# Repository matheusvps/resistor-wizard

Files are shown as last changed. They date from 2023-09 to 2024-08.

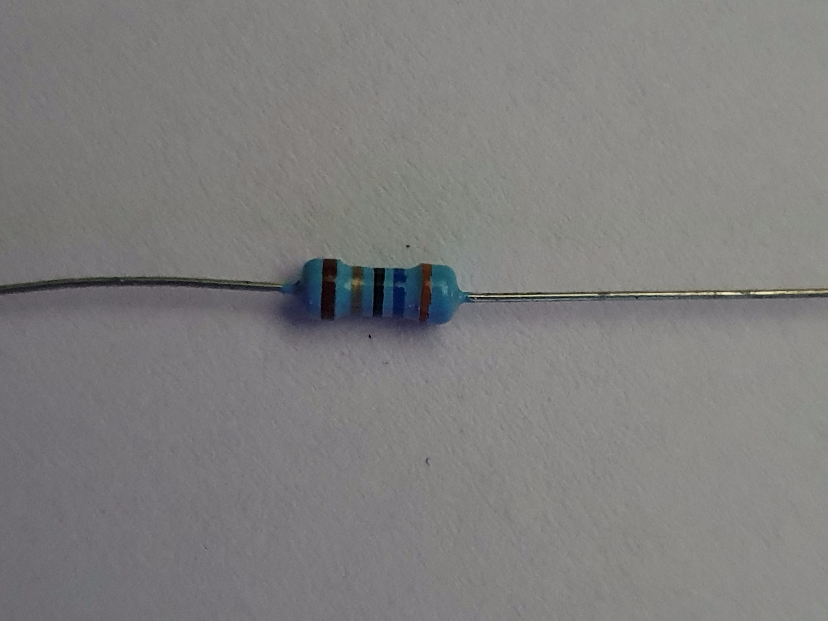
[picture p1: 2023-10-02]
Backend/Functionality Tests/0002.png

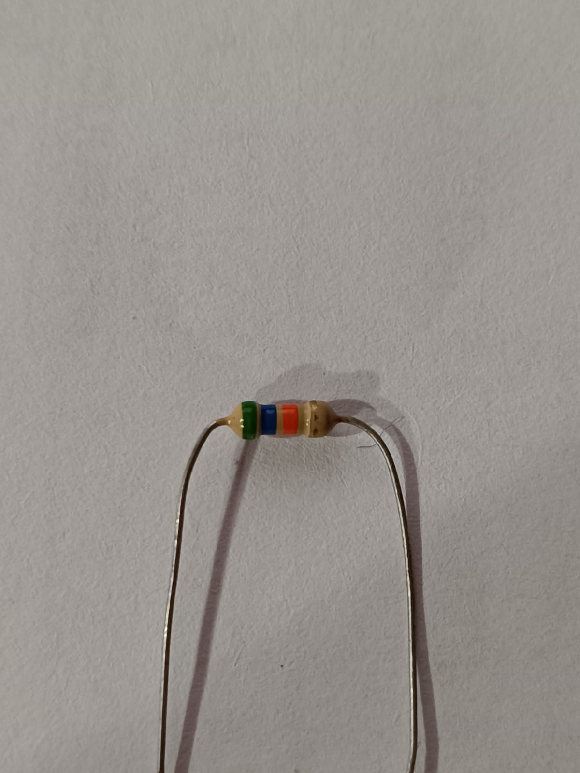
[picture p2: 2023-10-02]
Backend/Functionality Tests/0015.jpg

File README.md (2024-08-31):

# Resistor Wizard Project 🧙‍♂️

## Overview

This GitHub repository hosts the code for the Resistor Sorter project, developed as part of the Integration Workshops 1 subject. The system consists of a resistor sorting mechanism that allows users to insert indivual resistors into a small slit and select up to six resistance values to sort them into. It's implemented as a web application, with its frontend built using CSS, HTML, Javascript, and React framework. Both the server and subsequent backend processes are handled by a Raspberry Pi 3B running Flask in Python. The Pi photographs the resistors through a USB camera and extracts color and position data using Computer Vision (CV) to determine its resistance. To optimise the process of locating and classifying hue values under different lighting conditions, Machine Learning (ML) techniques were used.

## Team Members

- **Matheus Passos** - Frontend Development and Project Integration
- **Jhony Minetto** - Backend Development, Algorithm Design and ML Training
- **Ricardo Marthus** - Conception of 3D models and Image Labelling for the dataset

## Project Components

### Frontend

The frontend of the Resistor Wizard is composed of the web app user interface where resistance values can be selected and the hardware abd mechanical system controlled. The user interacts with the system primarily through this web interface.

### Backend

The backend of the project runs on a Raspberry Pi 3B server and is implemented in Python using the Flask framework. It handles the following tasks:

- Determining Resistor's position and color bands location using ML (YOLOv8 network trained on PyTorch ML framework)
- Color recognition using OpenCV
- Communication with the frontend

### Machine-Learning Models

The ML models are a crucial component of this project. They have been trained by our dedicated team to recognize resistors and resistor color bands accurately. The data used to train the models themselves is majoritarily self-provided (meaning we created and labelled the data ourselves). The complete datasets can be visited at <a href="https://universe.roboflow.com/uni-vug0c/metal-film-leaded-resistors-dataset">resistor dataset</a> and <a href="https://universe.roboflow.com/jhony-minetto-arajo/metal-film-leaded-resistor-color-bands">resistor color bands dataset</a>.

## Getting Started

To run this project locally or on your own Raspberry Pi server, follow these steps:

1. Clone this repository: `git clone https://github.com/yourusername/resistor-sorter.git`
2. Set up the frontend environment and dependencies.
   - Navigate to the `frontend` directory.
   - Install dependencies using npm or yarn: `npm install` or `yarn install`.
   - Start the frontend application: `npm start` or `yarn start`.
   
3. Set up the backend environment and dependencies on your Raspberry Pi.
   - Navigate to the `backend` directory.
   - Install Python dependencies: `pip install -r requirements.txt`.
   - Start the Flask server: `python app.py`.
   
4. Ensure the necessary hardware components are connected and configured on your Raspberry Pi for resistor input.

5. Access the web application in your browser and start using the Resistor Sorter.

## Contributions

We welcome contributions and improvements from the community. If you'd like to contribute to this project, please fork the repository, make your changes, and submit a pull request. Your contributions will be greatly appreciated.

Feel free to contact us if you have any questions or need assistance with the project.

Happy sorting!

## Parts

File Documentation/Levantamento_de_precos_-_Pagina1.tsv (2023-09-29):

Componentes | Quantidade | Custo Unitário R$ | Custo Total R$ | Adquirido
Raspberry Pi 3B | 1 | R$ 500,00 | R$ 500,00 | Sim
Motor de passo NEMA 17 | 2 | R$ 60,00 | R$ 120,00 | Sim
Driver de motor de passo | 2 | R$ 10,00 | R$ 20,00 | Sim
Kit 20 Placas MDF (150x210x3 mm) | 1 | R$ 32,00 | R$ 32,00 | Não
Placa de fenolite | 1 | R$ 10,00 | R$ 10,00 | Sim
Câmera Logitech 1080p | 1 | R$ 160,00 | R$ 160,00 | Sim
Placa de acrílico | 1 | R$ 30,00 | R$ 30,00 | Não
Resistores (cartela) | 1 | R$ 0,50 | R$ 0,50 | Sim
LEDs | 6 | R$ 0,30 | R$ 3,00 | Sim
MOSFET IRLZ44N | 1 | R$ 13,70 | R$ 13,70 | Sim
Regulador de tensão L7805 | 1 | R$ 3,30 | R$ 3,30 | Sim
Valor total |  |  | R$ 892,50

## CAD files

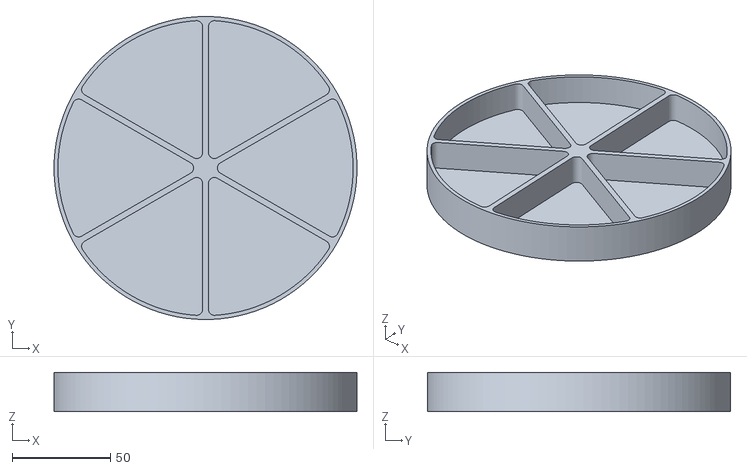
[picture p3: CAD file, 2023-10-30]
Backend/Modelos 3D/Armazenador.stl
154.0 x 154.0 x 20.0

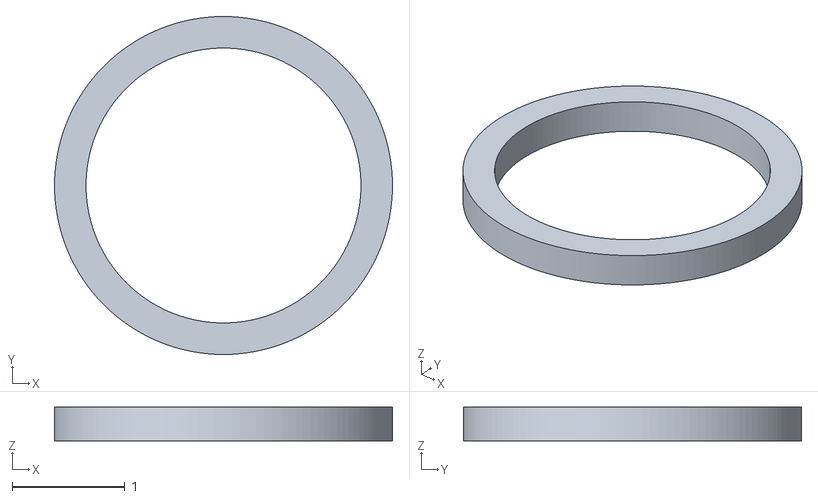
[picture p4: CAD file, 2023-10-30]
Backend/Modelos 3D/pcb_draw_test.stl
3.00 x 3.00 x 0.3

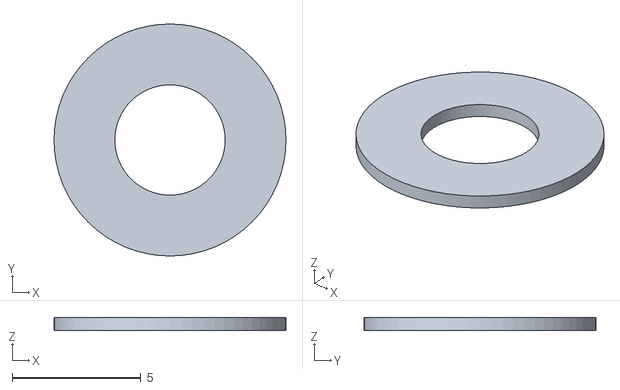
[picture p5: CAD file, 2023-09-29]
Backend/Modelos 3D/Arruela.stl
9.00 x 9.00 x 0.5

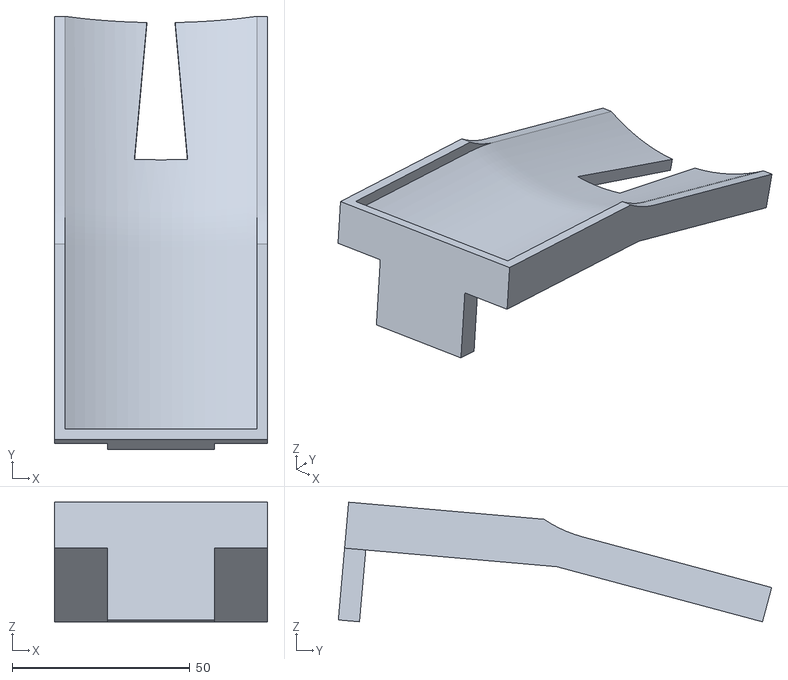
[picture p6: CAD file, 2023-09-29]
Backend/Modelos 3D/Dispenser_supported.stl
60.0 x 122.1 x 33.7

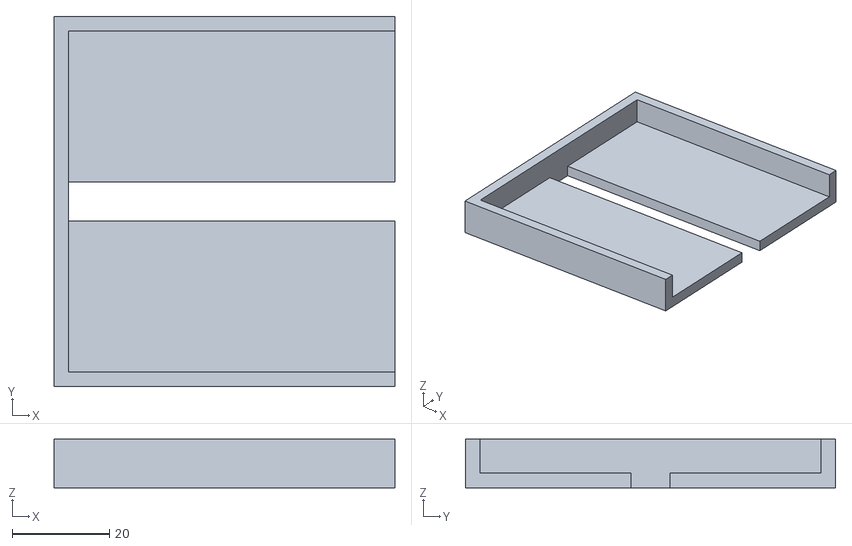
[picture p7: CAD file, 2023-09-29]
Backend/Modelos 3D/Dispenser_v3.stl
70.0 x 76.0 x 10.0

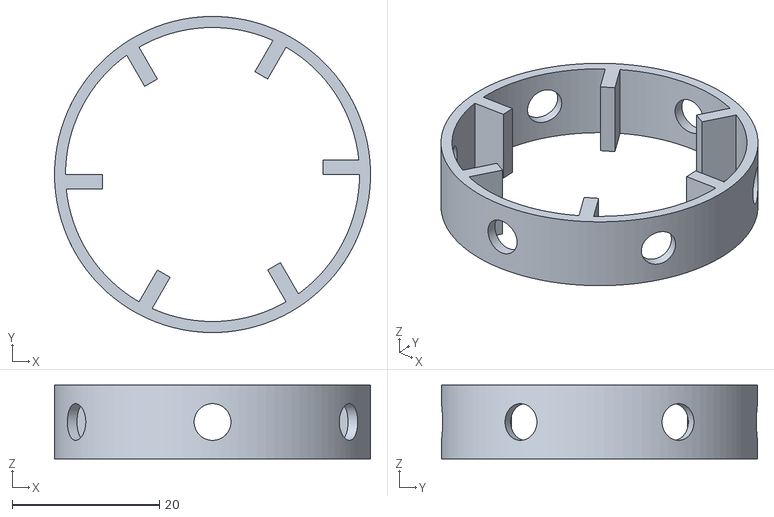
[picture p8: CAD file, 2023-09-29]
Backend/Modelos 3D/led_housing.stl
43.0 x 43.0 x 10.0

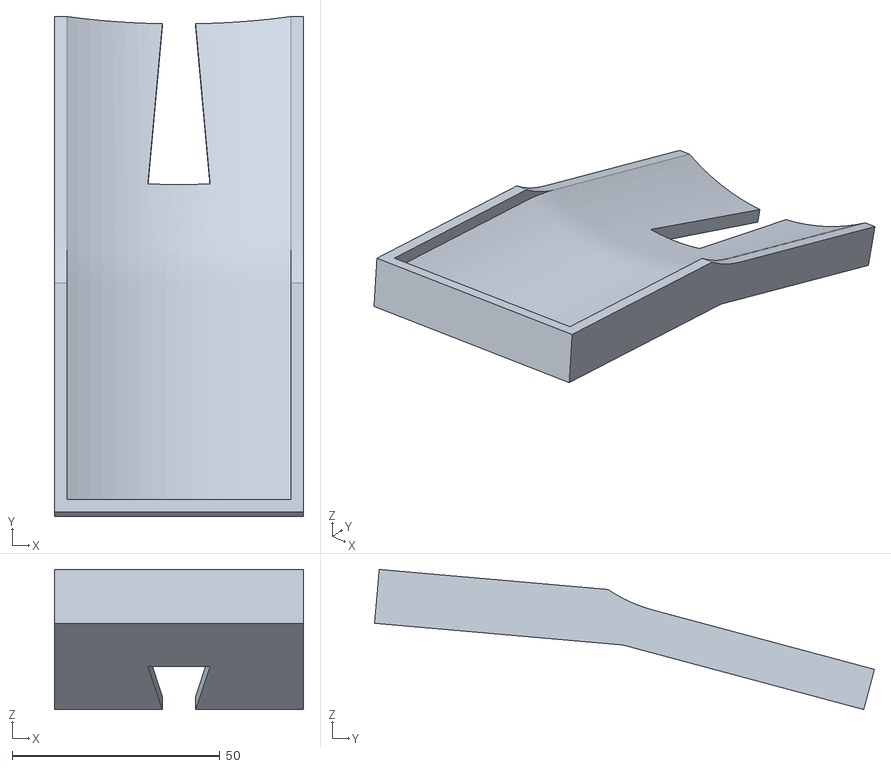
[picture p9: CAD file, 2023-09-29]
Backend/Modelos 3D/Dispenser.stl
60.0 x 120.3 x 33.7

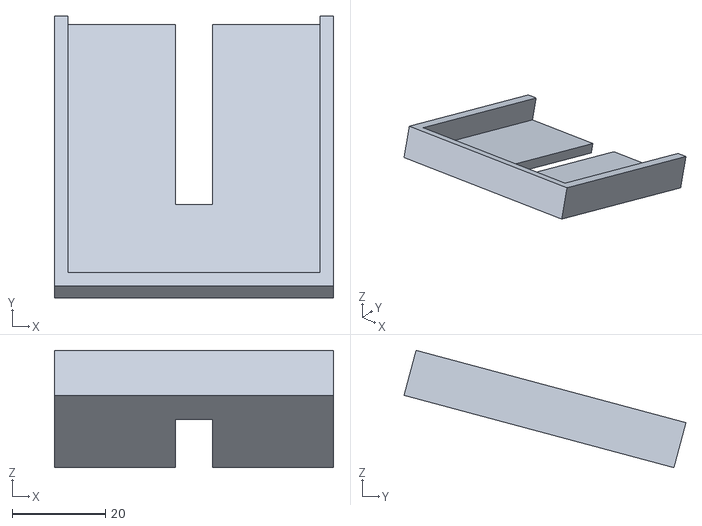
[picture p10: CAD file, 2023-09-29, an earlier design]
Backend/Modelos 3D/Dispenser_v2.stl
60.0 x 60.5 x 25.2

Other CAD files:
Backend/Modelos 3D/dispenser.blend

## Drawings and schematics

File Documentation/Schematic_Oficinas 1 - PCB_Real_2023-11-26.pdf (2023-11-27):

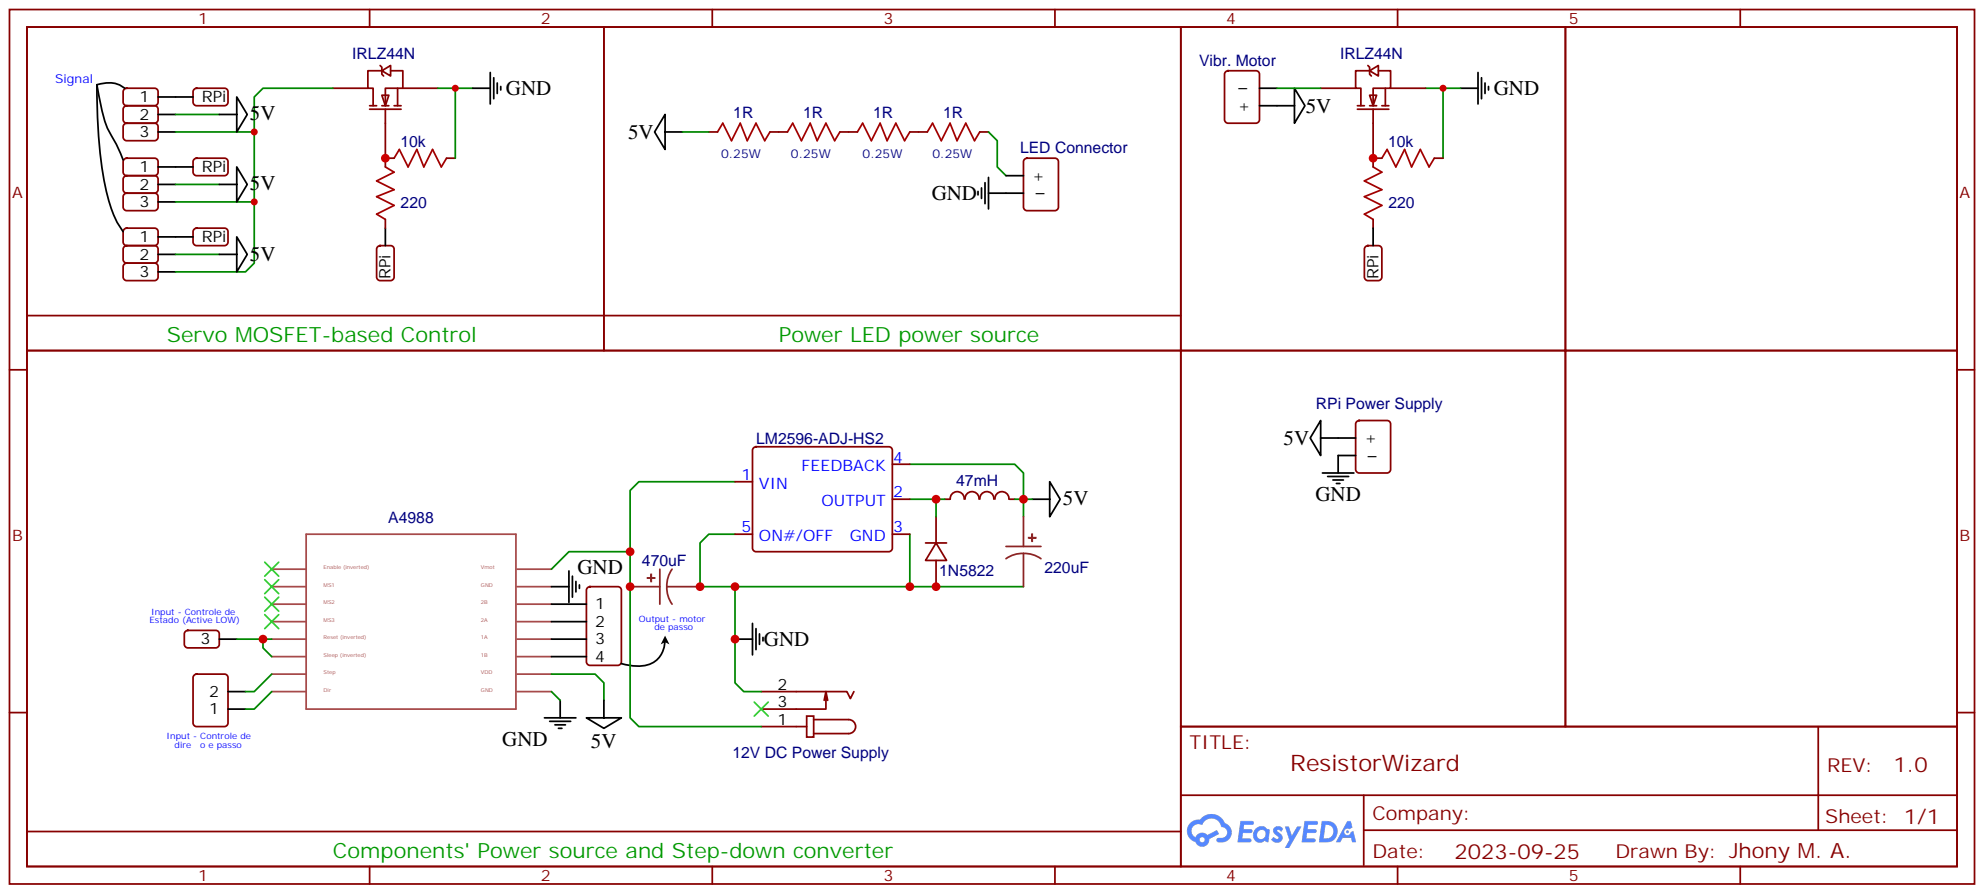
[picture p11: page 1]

Components' Power source and Step-down converter

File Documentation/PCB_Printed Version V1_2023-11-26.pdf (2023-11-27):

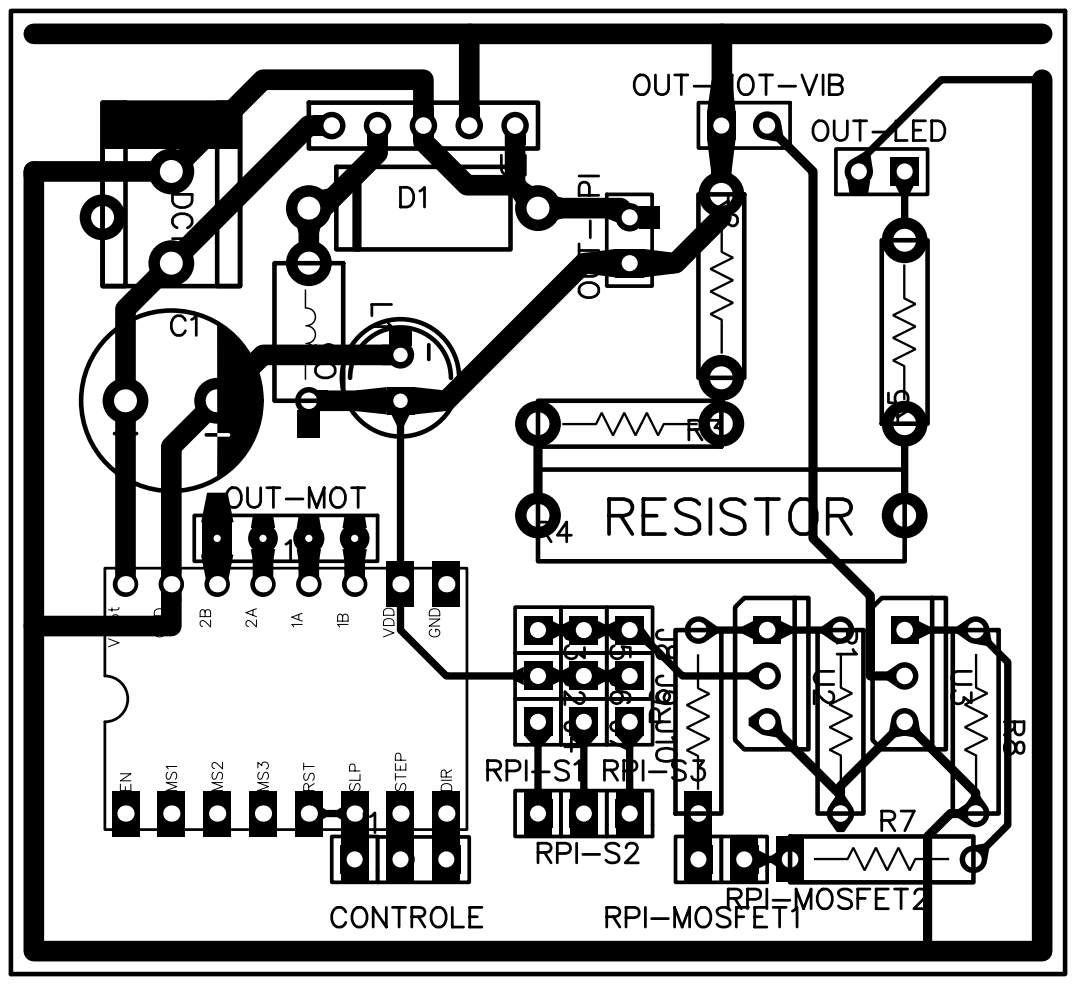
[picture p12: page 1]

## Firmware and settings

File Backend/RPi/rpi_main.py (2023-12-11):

# Main code for Raspberry Pi Model 3B+ -->
#  * Servos and motor control
#  * Camera and light control
#  * Resistor recognition
# ----------------------------------------------------------- #
from globals import *
from utils import *

# ----------------------------------------------------------- #
def run_receiver(rec: Receiver):
    rec.start()

def main():
    camera = Camera()
    motor = Motor(powerSaving=False)
    dispenser = Dispenser()
    plataforma = Plataforma()

    # 0: STOP
    # 1: RUNNING
    # 2: PAUSED
    # 3: EXIT
    is_running = Value('i', 0)  
    # Define the structure of the shared array (list of 5 dictionaries)
    array_size = 5

    # Create a shared array of bytes
    resistances = Array('i', array_size)
    margins = Array('i', array_size)

    receiver = Receiver(port=PORT, ip=IP, is_running=is_running, array_size=array_size, resistances=resistances, margins=margins)
    killer = Killer(is_running=is_running)
    killer.appendObj(camera)
    killer.appendObj(motor)
    killer.appendObj(dispenser)
    killer.appendObj(plataforma)
    killer.appendObj(GPIO)

    if '--no-server' not in sys.argv:
        receiver_process = Process(target=run_receiver, args=(receiver,))
        receiver_process.start()
        killer.appendProc(receiver_process)
    else:
        receiver.is_running.value = 1 # type: ignore
    
    # Loads Recognition models
    cropper = YOLO(yolo_cropper)
    color_bands = YOLO(yolo_segment)

    motor.home()
    camera.start()
    if '--no-renew' not in sys.argv:
        motor.move(100)  # Moves the motor to the position where the screw can be accessed for removal
        plataforma.eject()
    
    started = False
    while receiver.is_running.value != 3: # type: ignore
        while receiver.is_running.value != 1 and receiver.is_running.value != 3: # type: ignore
            sleep(0.1)
        
        if not started:  # Clears terminal window to facilitate reading
            os.system("clear")
            started = True

        for i in range(len(receiver.resistances)):
            motor.storages[i] = [receiver.resistances[i], receiver.margins[i], motor.storages[i][2]]
        print(f"Motor storages: {motor.storages}")

        no_resistor_accum = 0
        while receiver.is_running.value == 1 and no_resistor_accum < 3: # type: ignore
            if '--no-renew' not in sys.argv:
                with concurrent.futures.ThreadPoolExecutor() as executor:
                    func1 = executor.submit(dispenser.drop) # Drops ONE resistor onto the platform
                    func2 = executor.submit(motor.shake)  # Shakes the motor while dropping the resistor
                    # Wait for both to complete
                    concurrent.futures.wait([func1, func2])

            sleep(0.5)  # Waits for the resistor to fall onto the platform
            ret, frame = camera.capture()
            ret, frame = camera.capture()
            if not ret:
                for _ in range(3):
                    ret, frame = camera.capture()
                    if ret:
                        break
                    sleep(0.5)
                if not ret:
                    animate_dots("Couldn't retrieve frame from stream", duration=3)
                    raise Exception("Camera Failure.")
            
            oriented = check_orientation(frame)

            Image.fromarray(cv.cvtColor(oriented, cv.COLOR_BGR2RGB)).save(tmp_photo)

            resistor = dict()

            # Runs crop detection model on file
            cropped_infr = cropper(tmp_photo, conf=0.6)
            # Crops and saves original file to a temporary location
            if len(cropped_infr[0].boxes.data):
                print("\033[92m \n\tDetected a resistor\033[0m")
                cropped = cropImage(cv.imread(tmp_photo), cropped_infr[0].boxes.cpu().data[0])
                # Performs white-balancing on image
                balanced = white_balance(cropped)
                Image.fromarray(cv.cvtColor(balanced, cv.COLOR_BGR2RGB)).save(tmp_crop)
                # Runs color bands segmentation model on cropped inference
                colorbands_infr = color_bands(tmp_crop, conf=0.5, iou=0.3)

                try:
                    # Gets masks objects from the inference
                    masks = get_segmentation_masks(tmp_crop, colorbands_infr)
                    # Sorts the masks by distance (it doesn't have a way to 
                    #    know in which direction to start, so by default it 
                    #    uses the leftmost (0,0) point as a beginning.
                    ordered = order_masks(masks, colorbands_infr)

                    for i in range(len(ordered)):
                        color = retrieve_color(cvtBGR2HSV(ordered[i].avgColor))
                        resistor[i] = color
                        print(f"Index: {ordered[i].index} \t HSV: {cvtBGR2HSV(ordered[i].avgColor, paint=True)} \t Predicted: {color}")
                except Exception as e:
                    print(e)

                # Retrieves the resistance value and moves motor accordingly
                ret, resistance = get_resistance(resistor)
                print(f"\033[91m \n\tDetected Resistance: {resistance}\n\033[0m")
                found_slot = motor.find_slot(resistance)
                if not found_slot:
                    print(f"No suitable destination for the resistor...")
                no_resistor_accum = 0
            else:
                # Handles stopping condition when no resistors are 'seen' on image recognition
                no_resistor_accum += 1
                print(f"\033[91m\n\tCouldn't find a resistor, totalling {no_resistor_accum} empty images\n\033[0m")

            if '--no-renew' not in sys.argv:
                plataforma.eject()

    # CLOSING
    motor.move(100)  # Moves the motor to the position where the screw can be accessed for removal
    camera.__del__()
    dispenser.__del__()
    GPIO.__del__()
    if '--no-server' not in sys.argv:
        receiver_process.terminate()


if __name__=="__main__":
    main()

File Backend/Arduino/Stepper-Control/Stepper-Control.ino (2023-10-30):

/* Example sketch to control a stepper motor with A4988 stepper motor driver 
   and Arduino without a library. More info: https://www.makerguides.com */

// Define stepper motor connections and steps per revolution:
#define dirPin 2
#define stepPin 3
#define stepsPerRevolution 200

void setup() {
  // Declare pins as output:
  pinMode(stepPin, OUTPUT);
  pinMode(dirPin, OUTPUT);
}

void loop() {
  // Set the spinning direction clockwise:
  digitalWrite(dirPin, HIGH);

  // Spin the stepper motor 1 revolution slowly:
  for (int i = 0; i < stepsPerRevolution; i++) {
    // These four lines result in 1 step:
    digitalWrite(stepPin, HIGH);
    delayMicroseconds(2000);
    digitalWrite(stepPin, LOW);
    delayMicroseconds(2000);
  }

  delay(1000);

  // Set the spinning direction counterclockwise:
  digitalWrite(dirPin, LOW);

  // Spin the stepper motor 1 revolution quickly:
  for (int i = 0; i < stepsPerRevolution; i++) {
    // These four lines result in 1 step:
    digitalWrite(stepPin, HIGH);
    delayMicroseconds(1000);
    digitalWrite(stepPin, LOW);
    delayMicroseconds(1000);
  }

  delay(1000);

  // Set the spinning direction clockwise:
  digitalWrite(dirPin, HIGH);

  // Spin the stepper motor 5 revolutions fast:
  for (int i = 0; i < 5 * stepsPerRevolution; i++) {
    // These four lines result in 1 step:
    digitalWrite(stepPin, HIGH);
    delayMicroseconds(500);
    digitalWrite(stepPin, LOW);
    delayMicroseconds(500);
  }

  delay(1000);

  // Set the spinning direction counterclockwise:
  digitalWrite(dirPin, LOW);

  //Spin the stepper motor 5 revolutions fast:
  for (int i = 0; i < 5 * stepsPerRevolution; i++) {
    // These four lines result in 1 step:
    digitalWrite(stepPin, HIGH);
    delayMicroseconds(500);
    digitalWrite(stepPin, LOW);
    delayMicroseconds(500);
  }

  delay(1000);
}

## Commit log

2023-09-07 resistor colors detection - without dynamic image
2023-09-08 resistor color change
2023-09-29 Added Docs: reports, schematics and simulation objs
    [Levantamento_de_precos_-_Pagina1.tsv]
2023-09-29 Added Backend files to new repo: 3D models, development notebooks and latest models trained
    [Arruela.stl, Dispenser.stl, Dispenser_supported.stl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]
2023-10-02 Merged code base for Detection and Segmentation of resistors + Color classes classification added
    [BLACK.csv, BLUE.csv, BROWN.csv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]
2023-10-02 Fixed color averaging issues and updated CSV color classes extraction method
    [BLACK.csv, BLUE.csv, BROWN.csv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]
2023-10-02 Sampled more colors for classes + Trained segmentation model with newer images (dataset V10)
    [BLACK.csv, BLUE.csv, BROWN_DOWN.csv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]
2023-10-30 Profiled and optimised functions to use parallelization
    [Armazenador.stl, pcb_draw_test.stl]
2023-11-10 Stepper motor smooth(er) acceleration implemented
2023-11-11 Created class handlers for Stepper Motor, Dispenser and Camera objects
2023-11-13 Modified RPi main to account for "not changing" resistor for development mode
2023-11-23 Retrained Color Band classification model + CSV Lookup tables code
    [BLACK.csv, BLUE.csv, BROWN_DOWN.csv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]
2023-11-23 Motor Power Saving mode toggle option + concurrent motor and dispenser function
2023-11-23 Started implementation of motor movement based on resistance
2023-11-23 Stop loop on no resistors left + Motor movement perfected
2023-11-23 Strict linting + defined expected type of variables: UNTESTED
    [tmp.csv]
2023-11-24 Added different OS's implementation and optional server starting feature + Fixed camera index unavailable error
    [globals.py, gpio_conf.py, rpi_main.py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]
2023-11-25 Fixed Color class optimization code + Added light diffuser + Trained Grayscale recognition model
    [globals.py, optimize_lookup_table.py, rpi_main.py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]
2023-11-26 Modified Color class optimization + Primtive color classing
    [BLACK.csv, BLUE.csv, BROWN_DOWN.csv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]
2023-11-26 Fixing Color class arrangements
    [BLACK.csv, BLUE.csv, BROWN_DOWN.csv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]
2023-11-27 Implemented motors' vibration + improved color class categorization + semi-functional overall
    [BLACK.csv, BLUE.csv, BROWN_DOWN.csv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]
2023-12-11 Fixed frontend + Motor position on first eject
    [rpi_main.py]
